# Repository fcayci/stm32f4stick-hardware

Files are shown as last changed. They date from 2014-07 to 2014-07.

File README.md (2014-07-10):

# STM32F4Stick - An STM32F405/STM32F401 based development board - Hardware
This board is intended to be a small bread-board friendly development environment for STM32F4 series microcontrollers. There are different versions some of which are not tested. Please contact me if you see any problems or have any suggestions.

Current Version Features:
* 1.84 x 1.02 inches board size
* STM32F405RG ARM Microcontroller
* STM32F401 ARM Microcontroller compatible
* 16 MHz HSE Oscillator
* MiniUSB connector for power/programming (through bootloader)
* SD Card slot connected in SPI mode
* nRF24L01+ 2.4GHz radio module compatible header
* 1 x 16-pin breakout header and 1 x 6-pin header on both sides for easy breadboard development
* 2 x LEDs + 1 Push button
* Reset button
* Optional pull-ups on pins A10, B5, B11, and C11 for reliable USB bootloader
* Jump pads on BOOT0 pin, and push button on BOOT1 pin (Also act as a GPIO pin)

## Hardware Versions

### Version 2
---
##### Top side:
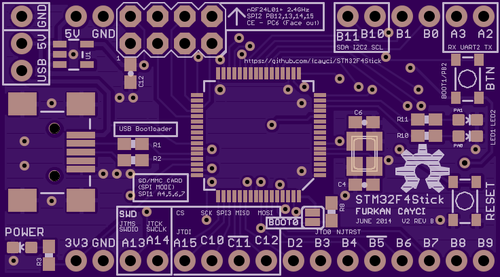
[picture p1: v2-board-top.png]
Version 2 - Top Side Top Side


##### Bottom side:
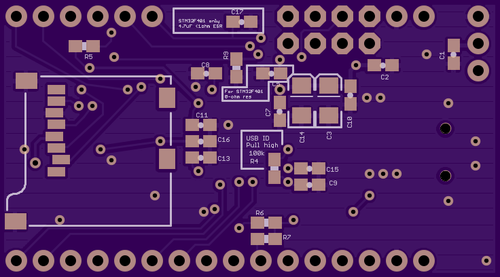
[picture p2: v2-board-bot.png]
Version 2 - Bottom Side Bottom Side


##### Changelog:

REV B:
* Added STM32F401 Compatibility. (R5/C5/C15/C17)
  * STM32F405:
    * Don't fit C17
    * R5 is optional pull-up
    * C5/C15 are 2.2uF ceramic capacitors
  * STM32F401:
    * Don't fit R5
    * C17 is 4.7uF ceramic capacitor
    * C5/C13 are 0 ohm resistors
    * PB11 pin is not available since it is changed to VCAP pin

REV A:
* 4x2-pin header for nRF24L01+ 2.4GHz radio connector
* 1.84 x 1.02 inches
* STM32F405RG ARM Microcontroller
* 16 MHz HSE Oscillator
* MiniUSB connector for power/programming (through bootloader)
* SD Card slot connected in SPI mode
* 1 x 16-pin breakout header and 1 x 6-pin header on both sides for easy breadboard development
* 2 x LEDs + 1 Push button
* Reset button
* Pull-ups on pins A10, B5, B11, and C11 for reliable USB bootloader
* Jump pads on BOOT0 pin, and push button on BOOT1 pin (Also act as a GPIO pin)

##### Pinout:

 Pin # | Pin Name | Functionality
------:|-----:|-------
 5  | PH0-OSC_IN | RCC_OSC_IN
 6  | PH1-OSC_OUT | RCC_OSC_OUT
 14 | PA0-WKUP | LED1
 15 | PA1 | LED2
 20 | PA4 | SPI1_NSS (SD Card)
 21 | PA5 | SPI1_SCK (SD Card)
 22 | PA6 | SPI1_MISO (SD Card)
 23 | PA7 | SPI1_MOSI (SD Card)
 28 | PB2 | BUTTON
 33 | PB12 | SPI2_NSS (nRF24L01+)
 34 | PB13 | SPI2_SCK (nRF24L01+)
 35 | PB14 | SPI2_MISO (nRF24L01+)
 36 | PB15 | SPI2_MOSI (nRF24L01+)
 37 | PC6 | CE (nRF24L01+)
 42 | PA9 | USB_OTG_FS_VBUS
 44 | PA11 | USB_OTG_FS_DM
 45 | PA12 | USB_OTG_FS_DP

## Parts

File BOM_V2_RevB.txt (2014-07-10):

Partlist exported from /Users/furkan/workcenter/eagle/projects/STM32F4Stick/STM32F4Stick.sch at 7/10/14 2:12 AM

Part   Value                   Device                   Package                  Description          
-1     USB-MINIB-5PIN          USB-MINIB-5PIN           USB-MINIB                Mini-USB "B" connect 
-2     STM32F405RG             STM32F405RG              TQFP64                   ARM DSP Chip used on 
-3     M04X2                   M04X2                    2X4                      .1" header, two rows 
C1     1.0uF                   1.0UF-16V-10%(0603)      0603-CAP                 CAP-00868            
C2     0.1uF                   0.1UF-25V-5%(0603)       0603-CAP                 CAP-08604            
C3     2.2uF                   CAP_POL1206              EIA3216                  Capacitor Polarized  
C4     20pF                    12PF-50V-5%(0603)        0603-CAP                 CAP-09137            
C5     2.2uF                   2.2UF-10V-20%(0603)      0603-CAP                 CAP-07888            
C6     20pF                    12PF-50V-5%(0603)        0603-CAP                 CAP-09137            
C7     0.1uF                   0.1UF-25V-5%(0603)       0603-CAP                 CAP-08604            
C8     0.1uF                   0.1UF-25V-5%(0603)       0603-CAP                 CAP-08604            
C9     0.1uF                   0.1UF-25V-5%(0603)       0603-CAP                 CAP-08604            
C10    0.1uF                   0.1UF-25V-5%(0603)       0603-CAP                 CAP-08604            
C11    0.1uF                   0.1UF-25V-5%(0603)       0603-CAP                 CAP-08604            
C12    1.0uF                   1.0UF-16V-10%(0603)      0603-CAP                 CAP-00868            
C13    0.1uF                   0.1UF-25V-5%(0603)       0603-CAP                 CAP-08604            
C14    4.7uF                   CAP_POL1206              EIA3216                  Capacitor Polarized  
C15    2.2uF                   2.2UF-10V-20%(0603)      0603-CAP                 CAP-07888            
C16    0.1uF                   0.1UF-25V-5%(0603)       0603-CAP                 CAP-08604            
C17    4.7uF                   4.7UF-6.3V-10%(0603)0603 0603-CAP                 CAP-08280            
D1     GREEN                   LED-GREEN0603            LED-0603                 Various green LEDs   
D2     BLUE                    LED-BLUE0603             LED-0603                 Blue LEDs for produc 
D3     RED                     LED-RED0603              LED-0603                 Assorted Red LEDs    
FRAME1 FRAME-LEDGER            FRAME-LEDGER             CREATIVE_COMMONS         Schematic Frame      
JP1    M161X16_NO_SILK         M161X16_NO_SILK          1X16_NO_SILK             1x16 .1" header      
JP2                            M031X03_NO_SILK          1X03_NO_SILK             Header 3             
JP3                            M06NO_SILK               1X06_NO_SILK             Header 6             
JP4    M021X02_NO_SILK         M021X02_NO_SILK          1X02_NO_SILK             Standard 2-pin 0.1"  
LOGO1  OSHW-LOGOM              OSHW-LOGOM               OSHW-LOGO-M              Open Source Hardware 
Q1                             XTAL-4-3225              NX3225                   Classic 4-pin 3.2 x  
R1     22                      22OHM1/10W1%(0603)       0603-RES                 RES-08698            
R2     22                      22OHM1/10W1%(0603)       0603-RES                 RES-08698            
R3     1K                      1KOHM1/10W1%(0603)       0603-RES                 RES-07856            
R4     100k                    100KOHM1/10W1%(0603)     0603-RES                 RES-07828            
R5     100k                    100KOHM1/10W1%(0603)     0603-RES                 RES-07828            
R6     100k                    100KOHM1/10W1%(0603)     0603-RES                 RES-07828            
R7     100k                    100KOHM1/10W1%(0603)     0603-RES                 RES-07828            
R8     10K                     10KOHM1/10W1%(0603)0603  0603-RES                 RES-00824            
R9     10K                     10KOHM1/10W1%(0603)0603  0603-RES                 RES-00824            
R10    1K                      1KOHM1/10W1%(0603)       0603-RES                 RES-07856            
R11    1K                      1KOHM1/10W1%(0603)       0603-RES                 RES-07856            
S1     SWITCH-MOMENTARY-2SMD-3 SWITCH-MOMENTARY-2SMD-3  TACTILE_SWITCH_SMD-3     Various NO switches- 
S2     SWITCH-MOMENTARY-2SMD-3 SWITCH-MOMENTARY-2SMD-3  TACTILE_SWITCH_SMD-3     Various NO switches- 
SJ1    JUMPER-PAD-2-NOYES_SILK JUMPER-PAD-2-NOYES_SILK  PAD-JUMPER-2-NO_YES_SILK                      
U1     MIC5219 3.3V            V_REG_MIC52193.3V        SOT23-5                  V_REG MIC5219        
U2     USD-SOCKETNEW           USD-SOCKETNEW            MICRO-SD-SOCKET-PP       microSD Socket

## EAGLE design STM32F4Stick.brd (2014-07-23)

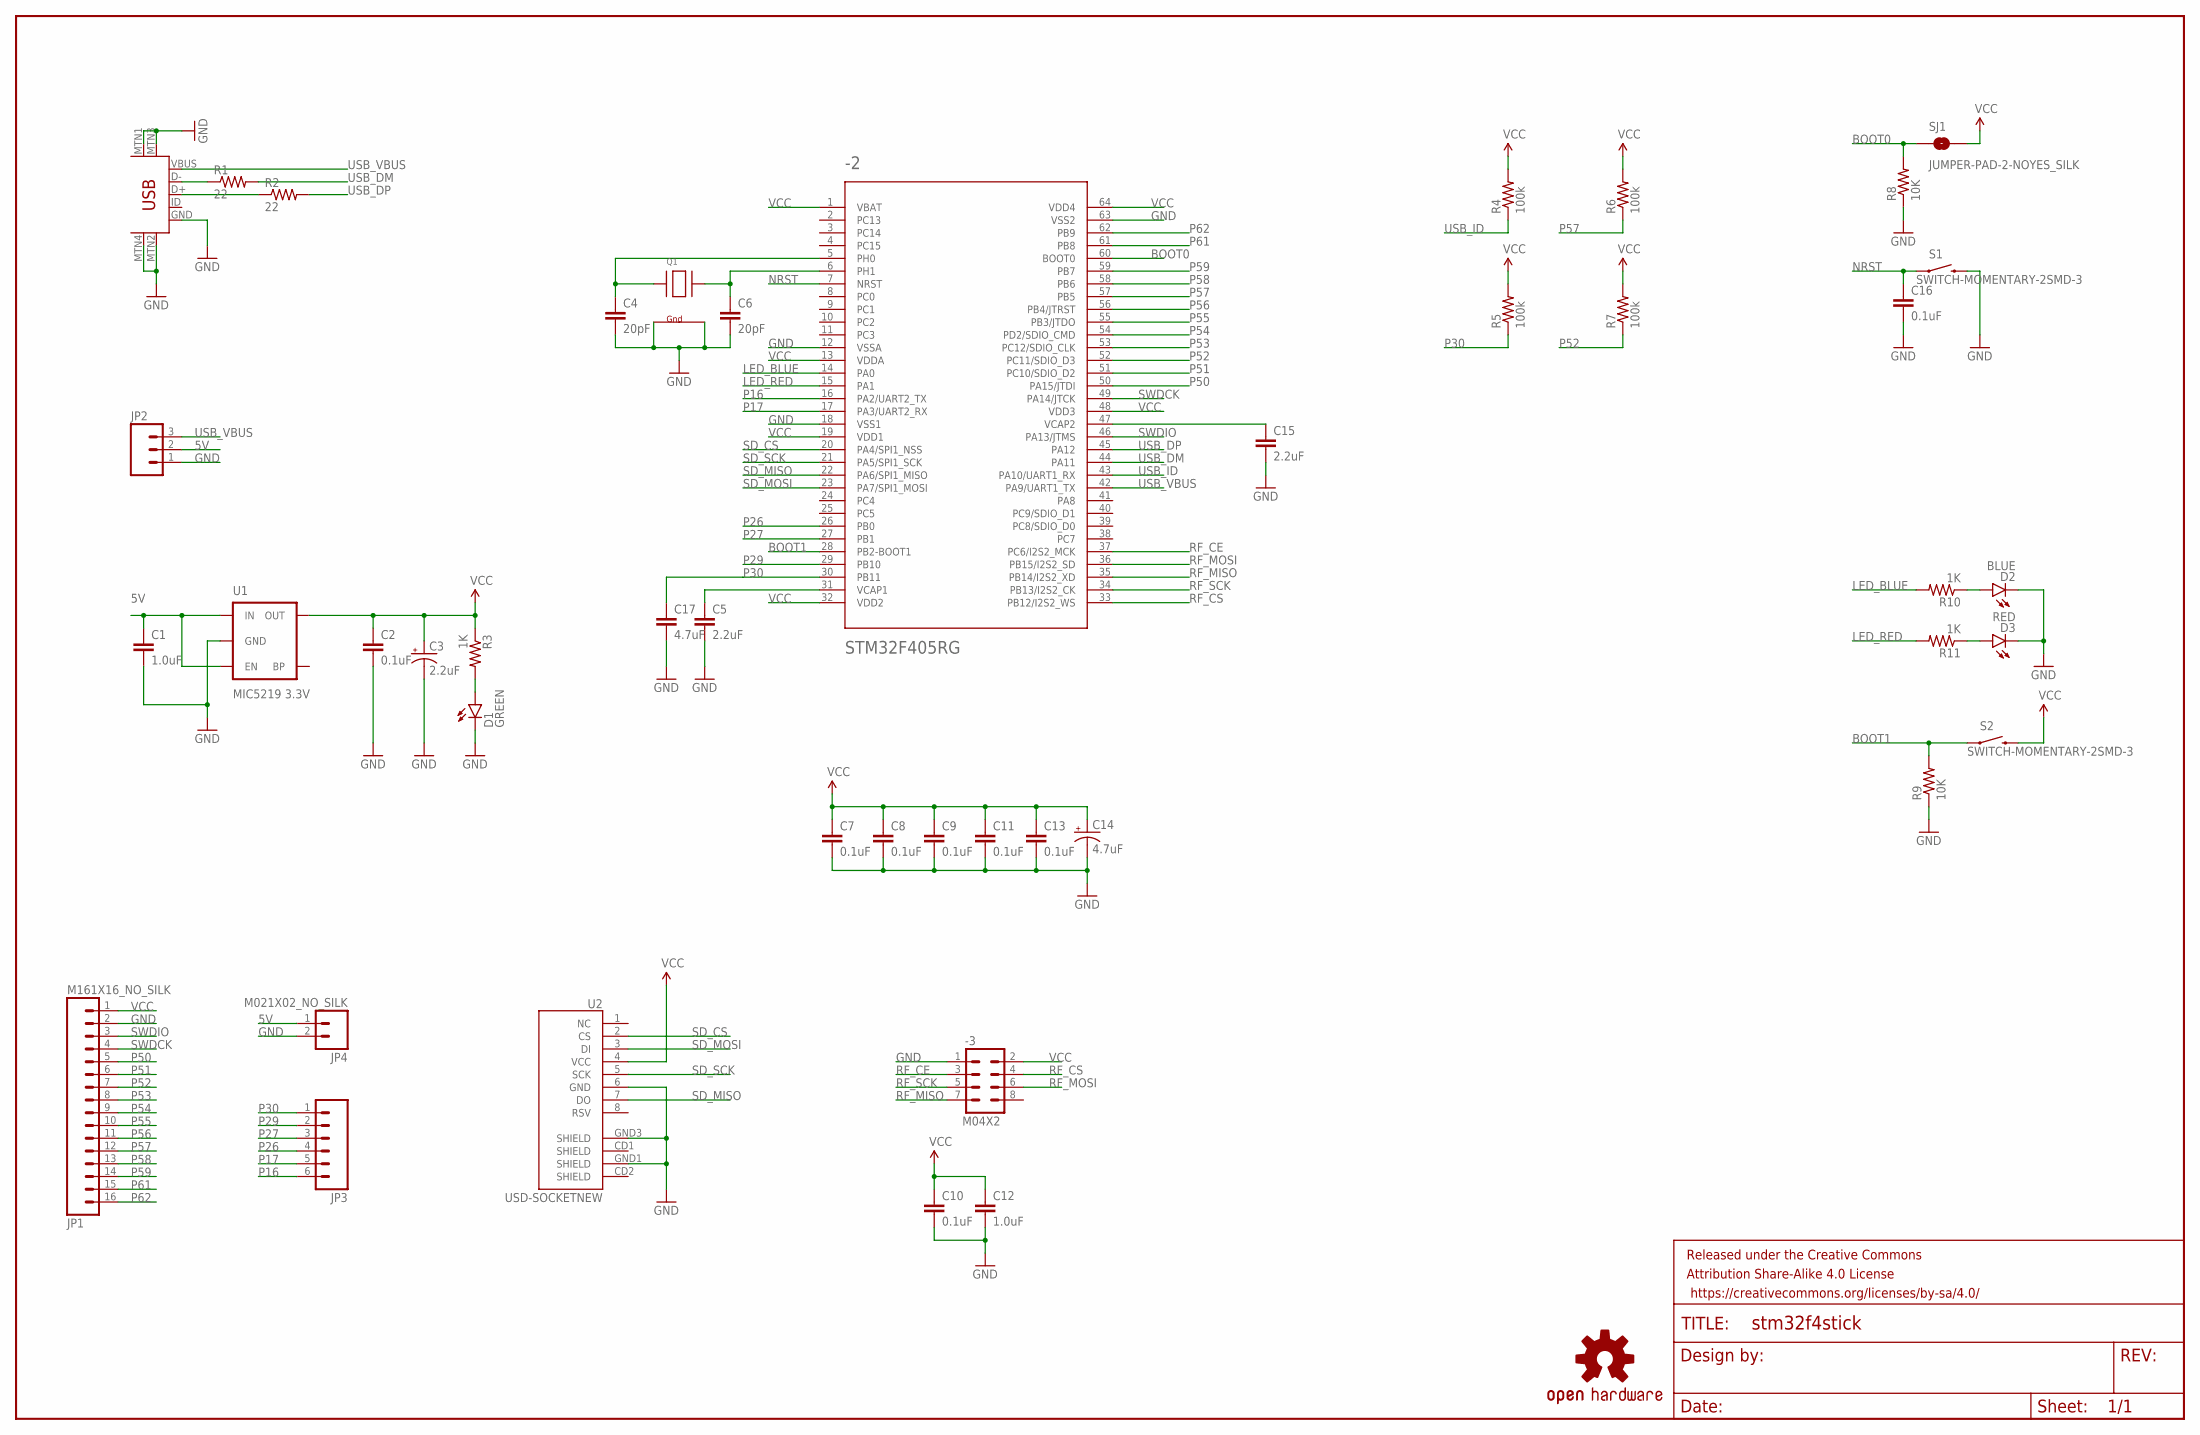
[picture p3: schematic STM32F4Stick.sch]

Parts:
-1: USB-MINIB-5PIN; USB-MINIB
-2: STM32F405RG; TQFP64
-3: M04X2; 2X4
C1, C12: 1.0uF; 0603-CAP
C2, C7, C8, C9, C10, C11, C13, C16: 0.1uF; 0603-CAP
C3: 2.2uF; EIA3216
C4, C6: 20pF; 0603-CAP
C5, C15: 2.2uF; 0603-CAP
C14: 4.7uF; EIA3216
C17: 4.7uF; 0603-CAP
D1: GREEN; LED-0603
D2: BLUE; LED-0603
D3: RED; LED-0603
FRAME1: FRAME-LEDGER; CREATIVE_COMMONS
JP1: M161X16_NO_SILK; 1X16_NO_SILK
JP2: M031X03_NO_SILK; 1X03_NO_SILK
JP3: M06NO_SILK; 1X06_NO_SILK
JP4: M021X02_NO_SILK; 1X02_NO_SILK
LOGO1: OSHW-LOGOM; OSHW-LOGO-M
Q1: XTAL-4-3225; NX3225
R1, R2: 22; 0603-RES
R3, R10, R11: 1K; 0603-RES
R4, R5, R6, R7: 100k; 0603-RES
R8, R9: 10K; 0603-RES
S1, S2: SWITCH-MOMENTARY-2SMD-3; TACTILE_SWITCH_SMD-3
SJ1: JUMPER-PAD-2-NOYES_SILK; PAD-JUMPER-2-NO_YES_SILK
U1: MIC5219 3.3V; SOT23-5
U2: USD-SOCKETNEW; MICRO-SD-SOCKET-PP

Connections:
5V: C1.1, JP2.2, JP4.1, U1.1 (IN), U1.3 (EN)
BOOT0: -2.60 (BOOT0), R8.2, SJ1.1
BOOT1: -2.28 (PB2-BOOT1), R9.2, S2.1
GND: -1.GND, -1.MTN1 (MTN2), -1.MTN2 (MTN3), -1.MTN3 (MTN1), -1.MTN4, -2.12 (VSSA), -2.18 (VSS1), -2.63 (VSS2), -3.1, C1.2, C2.2, C3.C (-), C4.2, C5.2, C6.2, C7.2, C8.2, C9.2, C10.2, C11.2, C12.2, C13.2, C14.C (-), C15.2, C16.2, C17.2, D1.C, D2.C, D3.C, JP1.2, JP2.1, JP4.2, Q1.2 (G2), Q1.4 (G1), R8.1, R9.1, S1.4 (2), U1.2 (GND), U2.6 (GND), U2.GND1 (SHIELD), U2.GND3 (SHIELD)
LED_BLUE: -2.14 (PA0), R10.2
LED_RED: -2.15 (PA1), R11.2
unnamed: -2.31 (VCAP1), C5.1
unnamed: -2.5 (PH0), C4.1, Q1.1 (X1)
unnamed: -2.6 (PH1), C6.1, Q1.3 (X2)
unnamed: -2.47 (VCAP2), C15.1
unnamed: D2.A, R10.1
unnamed: D3.A, R11.1
unnamed: D1.A, R3.2
unnamed: -1.D-, R1.1
unnamed: -1.D+, R2.1
NRST: -2.7 (NRST), C16.1, S1.1
P16: -2.16 (PA2/UART2_TX), JP3.6
P17: -2.17 (PA3/UART2_RX), JP3.5
P26: -2.26 (PB0), JP3.4
P27: -2.27 (PB1), JP3.3
P29: -2.29 (PB10), JP3.2
P30: -2.30 (PB11), C17.1, JP3.1, R5.1
P50: -2.50 (PA15/JTDI), JP1.5
P51: -2.51 (PC10/SDIO_D2), JP1.6
P52: -2.52 (PC11/SDIO_D3), JP1.7, R7.1
P53: -2.53 (PC12/SDIO_CLK), JP1.8
P54: -2.54 (PD2/SDIO_CMD), JP1.9
P55: -2.55 (PB3/JTDO), JP1.10
P56: -2.56 (PB4/JTRST), JP1.11
P57: -2.57 (PB5), JP1.12, R6.1
P58: -2.58 (PB6), JP1.13
P59: -2.59 (PB7), JP1.14
P61: -2.61 (PB8), JP1.15
P62: -2.62 (PB9), JP1.16
RF_CE: -2.37 (PC6/I2S2_MCK), -3.3
RF_CS: -2.33 (PB12/I2S2_WS), -3.4
RF_MISO: -2.35 (PB14/I2S2_XD), -3.7
RF_MOSI: -2.36 (PB15/I2S2_SD), -3.6
RF_SCK: -2.34 (PB13/I2S2_CK), -3.5
SD_CS: -2.20 (PA4/SPI1_NSS), U2.2 (CS)
SD_MISO: -2.22 (PA6/SPI1_MISO), U2.7 (DO)
SD_MOSI: -2.23 (PA7/SPI1_MOSI), U2.3 (DI)
SD_SCK: -2.21 (PA5/SPI1_SCK), U2.5 (SCK)
SWDCK: -2.49 (PA14/JTCK), JP1.4
SWDIO: -2.46 (PA13/JTMS), JP1.3
USB_DM: -2.44 (PA11), R1.2
USB_DP: -2.45 (PA12), R2.2
USB_ID: -2.43 (PA10/UART1_RX), R4.1
USB_VBUS: -1.VBUS, -2.42 (PA9/UART1_TX), JP2.3
VCC: -2.1 (VBAT), -2.13 (VDDA), -2.19 (VDD1), -2.32 (VDD2), -2.48 (VDD3), -2.64 (VDD4), -3.2, C2.1, C3.A (+), C7.1, C8.1, C9.1, C10.1, C11.1, C12.1, C13.1, C14.A (+), JP1.1, R3.1, R4.2, R5.2, R6.2, R7.2, S2.4 (2), SJ1.2, U1.5 (OUT), U2.4 (VCC)

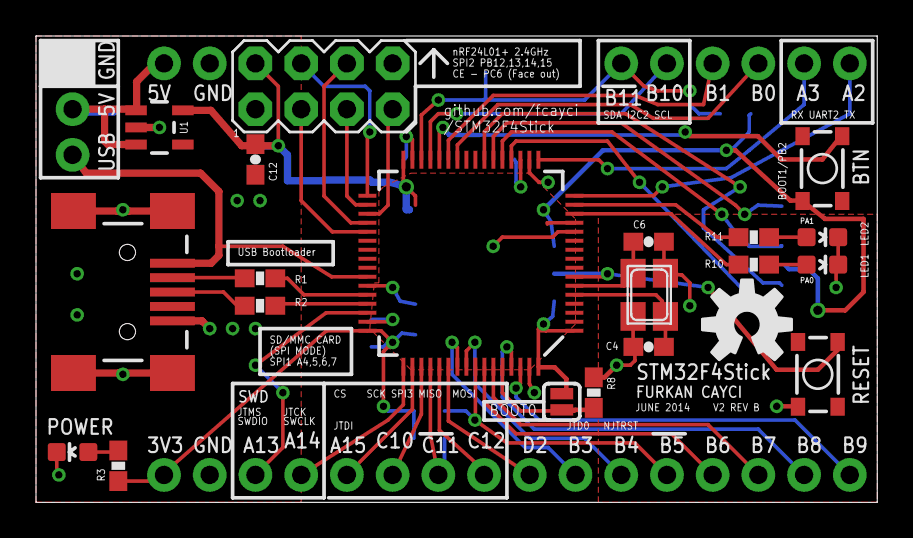
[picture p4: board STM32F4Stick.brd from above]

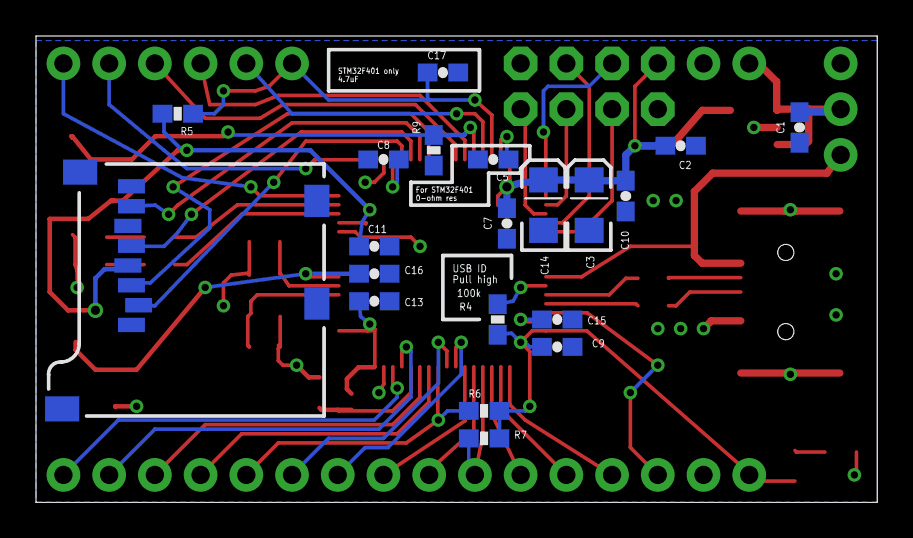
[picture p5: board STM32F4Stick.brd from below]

Board: 2 copper layers, 46.7 x 25.9 mm, 46 parts (20 on the bottom side), 50 nets.

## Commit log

2014-06-29 STM32F405 ARM Development Board. Schematic RevA. Should have everything to get the chip working.
    [STM32F4Stick.sch]
2014-06-29 Board layout is almost complete. Needs extension header pins and silkscreen stuff.
    [STM32F4Stick.brd, STM32F4Stick.sch]
2014-06-30 Extension header additions to schematic. Routing is complete on the board. The second extension header connections needs to be added.
    [STM32F4Stick.brd, STM32F4Stick.sch]
2014-06-30 Added SD-Card. Still need to route the extension pins.
    [STM32F4Stick.brd, STM32F4Stick.sch]
2014-06-30 Finished Schematic / Board layout. Silkscreen needs to be added
    [STM32F4Stick.brd, STM32F4Stick.sch]
2014-06-30 Final version for Rev A.
    [STM32F4Stick.brd, STM32F4Stick.sch]
2014-06-30 Small fixes to the usb resistors and a component might get in the way of SD card slot.
    [STM32F4Stick.brd]
2014-06-30 Final Rev B. Added nRF24L01+ 2.4GHz radio compatible header. Got rid of some of the extension headers. Check out RevA if you do not need to use nRF24L01+ radio but instead have extension headers.
    [STM32F4Stick.brd, STM32F4Stick.sch]
2014-07-03 Readme additions. Added a lot of information about V1 and V2 boards.
2014-07-09 adeed STM32F401 chip support to schematic only
    [STM32F4Stick.brd, STM32F4Stick.sch]
2014-07-10 V2 RevB final. Finalize stm32f401 support on version 2 board.
    [STM32F4Stick.brd, STM32F4Stick.sch]
2014-07-10 Version 2 RevB. Added BOM. Added RevB images. Added fab files. Readme changes.
2014-07-16 Ver2 RevB. Made changes to some silkscreen lines thinner.
    [STM32F4Stick.brd]
2014-07-23 button fix
    [STM32F4Stick.brd, STM32F4Stick.sch]

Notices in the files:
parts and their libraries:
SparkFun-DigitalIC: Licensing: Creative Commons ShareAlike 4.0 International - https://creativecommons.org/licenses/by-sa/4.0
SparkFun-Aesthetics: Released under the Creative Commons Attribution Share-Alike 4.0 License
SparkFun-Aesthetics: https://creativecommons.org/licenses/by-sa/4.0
